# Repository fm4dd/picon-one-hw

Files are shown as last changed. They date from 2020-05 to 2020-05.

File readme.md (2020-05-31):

## PiCon-One

### Description

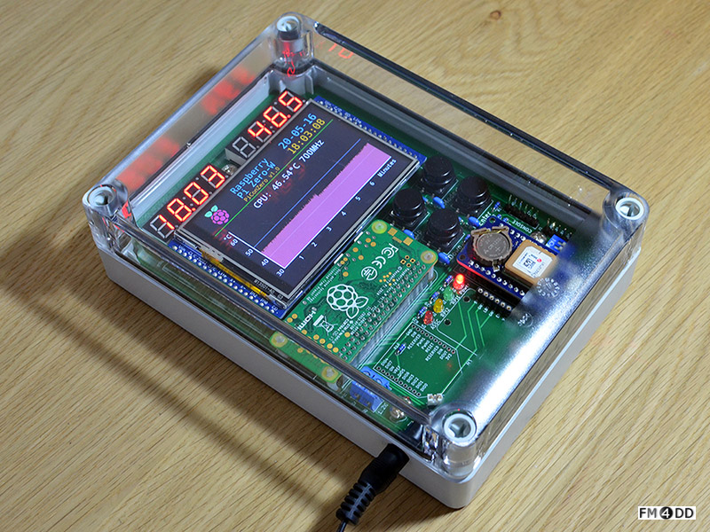
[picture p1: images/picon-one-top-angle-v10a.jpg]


PiCon-One is a multi-function controller for automation and industrial use cases.
At its heart is the smallest member of the Raspberry family, the Raspberry Pi Zero W.
Instead of adding a "hat" on top of the Raspberry, I reversed the roles:
The Pi becomes the "hat" for the controller mainboard, which has been fitted to 
a Takachi enclosure.

The design aims to add flexible power configuration, real-time clock, GPS positioning,
display and communication interfaces, enabling rapid prototyping under the widespread
Raspberry Pi ecosystem.

### Schematic
[PiCon-One Schematics](picon-one-schematics-v10a.pdf)

### PCB Gerber

Layers: 2
Dimension: 118mm x 168mm
PCB Thickness: 1.6
PCB Color: Green
Surface Finish: LeadFree HASL-RoHS
Copper Weight: 1
Material: FR4-Standard Tg 130-140C
Gerber: [PiCon-One Gerber V1.0a](picon-one-gerber-v10a.zip)

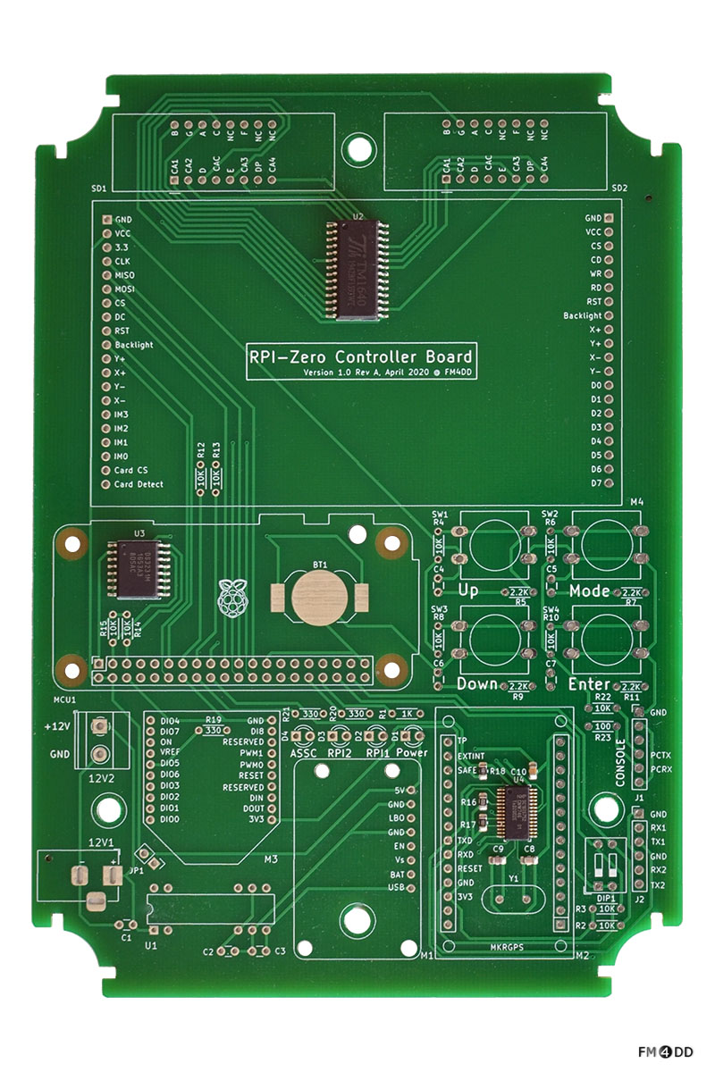
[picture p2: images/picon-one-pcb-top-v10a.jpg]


### Components Layout

Takachi Enclosure: SPCP131805T, 125mm x 175mm x 50mm

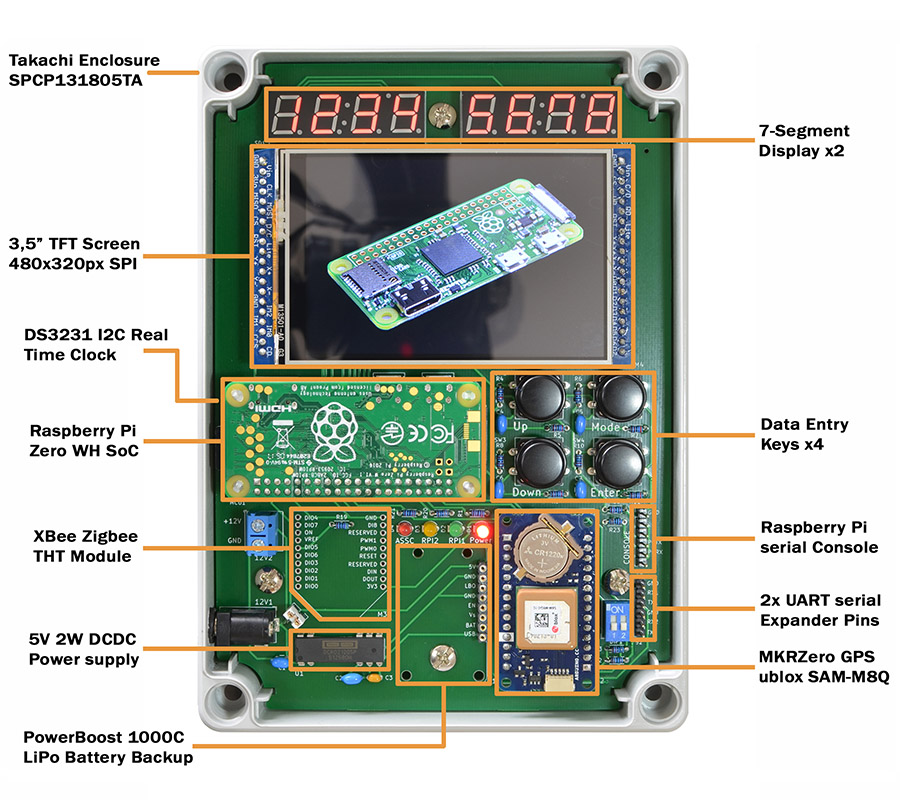
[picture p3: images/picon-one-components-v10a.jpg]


### Bill of Materials

[BOM file PiCon-One v1.0a](./picon-one-bom-v10a.csv)

### Assembly

SMT parts assembly has been combined with PCB manufacturing. 
Remaining is the THT parts assembly.

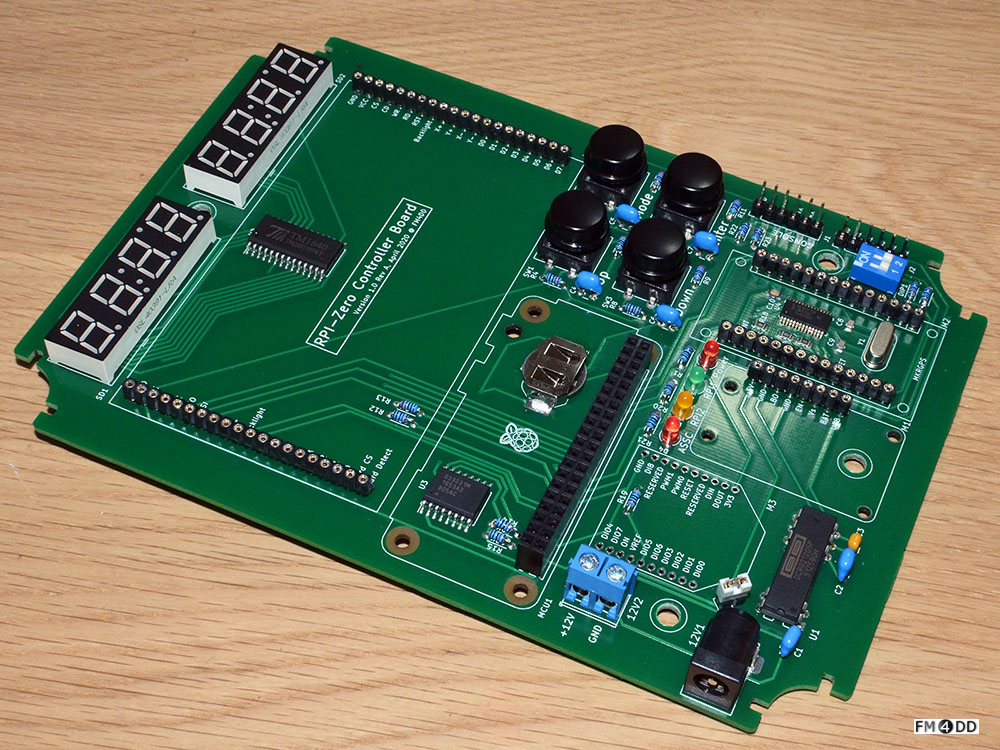
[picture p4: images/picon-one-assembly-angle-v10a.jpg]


#### Software and Drivers

Example software and setup is kept in a separate github repo at
https://github.com/fm4dd/picon-one-sw

### License

CERN Open Hardware Licence v1.2

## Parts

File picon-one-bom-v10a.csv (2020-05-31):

Item | Qty | Reference | Part Description | Type | Manufacturer | Manufacturer Part-# | Distributor | Distributor Part-#
1 | 1 | D2 | LED Green Diffused 3mm round | THT | Wurth Electronics Inc. | 151031VS06000 | Digi-Key | 732-5008-ND
2 | 1 | D3 | LED Yellow Diffused 3mm round | THT | Wurth Electronics Inc. | 151031YS06000 | Digi-Key | 732-5010-ND
3 | 1 | R20 | RES 330 OHM 1/4W 1% AXIAL | THT | Stackpole Electronics Inc | RNMF14FTC330R | Digi-Key | S330CACT-ND
4 | 1 | R21 | RES 220 OHM 1/4W 1% AXIAL | THT | Stackpole Electronics Inc | RNMF14FTC220R | Digi-Key | S220CACT-ND
5 | 1 | R22 | RES 10K OHM 1/4W 1% AXIAL | THT | Stackpole Electronics Inc | RNMF14FTC10K0 | Digi-Key | S10KCACT-ND
6 | 1 | R23 | RES 100 OHM 1/4W 1% AXIAL | THT | Stackpole Electronics Inc | RNMF14FTC100R | Digi-Key | S100CACT-ND
7 | 2 | J1, J2 | 2x 2.54-pin x6 header for serial pinout | THT | N/A | N/A | Digi-Key | N/A
Item | Qty | Reference | Part Description | Type | Manufacturer | Manufacturer Part-# | Distributor | Distributor Part-#
8 | 1 | 12V1 | Barrel Jack Connector 2.1mm | THT | CUI Inc. | PJ-002A | Digi-Key | CP-002A-ND
9 | 1 | 12V2 | TERM BLK 2P SIDE ENT 5.08MM PCB | THT | On Shore Technology Inc. | OSTTC022162 | Digi-Key | ED2609-ND
10 | 1 | U1 | DC DC CONVERTER 5V 2W | THT | Texas Instruments | DCR021205P | Digi-Key | 296-36927-5-ND
11 | 1 | C1 | CAP CER 2.2pF 50V C0G Radial | THT | TDK | FG28C0G1H2R2CNT06 | Digi-Key | 445-173491-1-ND
12 | 1 | C2 | CAP CER 1UF 50V X8L Radial | THT | KEMET | C320C105K5N5TA91707301 | Digi-Key | 399-14394-1-ND
13 | 1 | C3 | CAP CER 0.1UF 50V X7R RADIAL | THT | AVX | SR215C104KAT | Digi-Key | SR215C104KAT-ND
14 | 1 | R1 | RES 1K OHM 1/4W 1% AXIAL | THT | Stackpole Electronics Inc | RNMF14FTC1K0 | Digi-Key | S1KCACT-ND
15 | 1 | D1 | LED Red Diffused 3mm round | THT | Wurth Electronics Inc. | 151031SS04000 | Digi-Key | 732-5005-ND
16 | 1 | M1 | PWRBOOST 1000 5V LIPO USB | THT | Adafruit Industries LLC | 2465 | Digi-Key | 1528-1349-ND
17 | 1 | JP1 | 2x 2.54-pin header and Jumper | THT |  |  | Digi-Key
Item | Qty | Reference | Part Description | Type | Manufacturer | Manufacturer Part-# | Distributor | Distributor Part-#
18 | 1 | M2 | Arduino MKR GPS Shield | THT | Arduino | ASX00017 | Digi-Key | 1050-1171-ND
Item | Qty | Reference | Part Description | Type | Manufacturer | Manufacturer Part-# | Distributor | Distributor Part-#
19 | 2 | DS1, DS2 | 0.39 Inch 4-Digit 7-Segment Display | THT | OptoSupply | OSL40391-LRA | Akizuki | I-09971
20 | 1 | U2 | TM1640 LED driver IC | SMT | Titan Microelectronics | TM1640 | LCSC | C41327
21 | 2 | R12, R13 | RES 10K OHM 1/4W 1% AXIAL | THT | Stackpole Electronics Inc | RNMF14FTC10K0 | Digi-Key | S10KCACT-ND
Item | Qty | Reference | Part Description | Type | Manufacturer | Manufacturer Part-# | Distributor | Distributor Part-#
22 | 1 | DIP1 | DIP SWITCH, SPST, 2.54 PITCH, RA | THT | CUI Devices | DS01-254-S-02BE | Digi-Key | 2223-DS01-254-S-02BE-ND
23 | 4 | SW1-SW4 | 12mm SWITCH TACTILE SPST-NO 0.05A 24V | THT | TE Connectivity | FSM103 | Digi-Key | 450-1158-ND
24 | 4 | C4, C5, C6, C7 | CAP CER 1UF 50V X8L Radial | THT | KEMET | C320C105K5N5TA91707301 | Digi-Key | 399-14394-1-ND
25 | 6 | R2-4, R6, R8, R10 | RES 10K OHM 1/4W 1% AXIAL | THT | Stackpole Electronics Inc | RNMF14FTC10K0 | Digi-Key | S10KCACT-ND
26 | 4 | R5, R7, R9, R11 | RES 2K2 OHM 1/4W 1% AXIAL | THT | Stackpole Electronics Inc | RNMF14FAD2K20 | Digi-Key | RNMF14FAD2K20CT-ND
Item | Qty | Reference | Part Description | Type | Manufacturer | Manufacturer Part-# | Distributor | Distributor Part-#
27 | 1 | M3 | Xbee RF TXRX Module S2C | THT | Digi International | XB24CZ7PIT-004 | Digi-Key | 602-1557-ND
28 | 1 | R19 | RES 330 OHM 1/4W 1% AXIAL | THT | Stackpole Electronics Inc | RNMF14FTC330R | Digi-Key | S330CACT-ND
29 | 1 | D4 | LED Red Diffused 3mm round | THT | Wurth Electronics Inc. | 151031SS04000 | Digi-Key | 732-5005-ND
Item | Qty | Reference | Part Description | Type | Manufacturer | Manufacturer Part-# | Distributor | Distributor Part-#
30 | 1 | MCU1 | Raspberry Pi Zero W BCM2835 | NA | Pi Supply | RPI-027 | Digi-Key | 1910-1000-ND
31 | 1 | N/A | CONN RCPT 40POS 0.1 TIN PCB | THT | Harwin Inc. | M20-7832046 | Digi-Key | 952-2150-ND
32 | 4 | N/A | BOARD SUPRT SNAP LOCK NYLON 11MM | NA | W�rth Elektronik | 709670110 | Digi-Key | 732-10378-ND
Item | Qty | Reference | Part Description | Type | Manufacturer | Manufacturer Part-# | Distributor | Distributor Part-#
33 | 1 | M4 | 3.5" TFT 320X480 Touchscreen | THT | Adafruit Industries LLC | 2050 | Digi-Key | 1528-1470-ND
34 | 1 | N/A | 40-pin Socket 2.54mm single row | THT | Neltron Industrial Co., Ltd. | 6604-S | Akizuki | P-01591
35 | 2 | N/A | 2.54mm Pin Header Strip, Straight, Single Row | THT | Useconn Electronics, Ltd | PHA-1x40SG-XX | Akizuki | C-06637
Item | Qty | Reference | Part Description | Type | Manufacturer | Manufacturer Part-# | Distributor | Distributor Part-#
36 | 1 | U3 | DS3231 I2C Real Time Clock IC | SMT | Maxim Integrated | DS3231M+TRL | LCSC | C37663
37 | 1 | BT1 | BATTERY RETAINER COIN 12MM SMD | SMT | Linx Technologies Inc. | BAT-HLD-012-SMT | Digi-Key | BAT-HLD-012-SMT-ND
38 | 2 | R14, R15 | RES 10K OHM 1/4W 1% AXIAL | THT | Stackpole Electronics Inc | RNMF14FTC10K0 | Digi-Key | S10KCACT-ND
Item | Qty | Reference | Part Description | Type | Manufacturer | Manufacturer Part-# | Distributor | Distributor Part-#
39 | 1 | N/A | SPCP IP67 POLYCARBONATE ENCLOSURE | NA | Takachi | SPCP131805T | Amazon | N/A
40 | 4 | N/A | MACH SCREW BINDING HEAD COMBO M4 | NA | Keystone Electronics | 7799-1 | Digi-Key | 36-7799-1-ND
Item | Qty | Reference | Part Description | Type | Manufacturer | Manufacturer Part-# | Distributor | Distributor Part-#
41 | 1 | U4 | SC16IS752 Dual UART IC | SMT | NXP | SC16IS752IPW,128 | Digi-Key | 568-11944-1-ND
42 | 1 | Y1 | CRYSTAL 14.74560MHZ 30PF | THT | IQD Frequency Products | LFXTAL003224BULK | Digi-Key | 1923-1432-ND
43 | 1 | C8 | CAP 22pF 10% 50V X7R C_0805 | SMT | Samsung | CL21C220JBANNNC | LCSC | C1804
44 | 1 | C9 | CAP 33pF 5% 50V C_0805 | SMT | Samsung | CL21C330JBANNNC | LCSC | C1814
45 | 1 | C10 | CAP 100nF 5% 50V X7R C_0805 | SMT | Samsung | CL21B104JBCNNNC | LCSC | C62912
46 | 1 | R16 | RES 10K OHM 1% R_0805 | SMT | Uniroyal Elec | 0805W8F1002T5E | LCSC | C17414
47 | 2 | R17,R18 | RES 1K OHM 1% R_0805 | SMT | Uniroyal Elec | 0805W8F1001T5E | LCSC | C17513

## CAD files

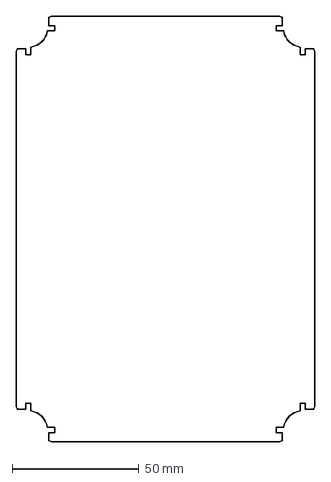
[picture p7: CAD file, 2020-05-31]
cad/20200419 pcb board outline v1.0.dxf
117.8 x 168.0 mm

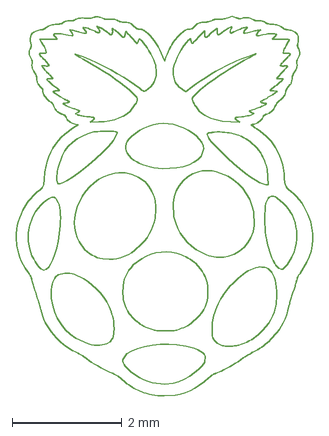
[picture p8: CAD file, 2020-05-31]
cad/20200308 raspi-logo.dxf
5.40 x 6.91 mm

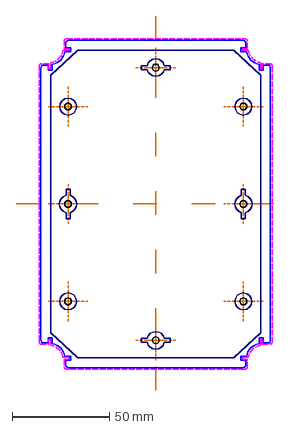
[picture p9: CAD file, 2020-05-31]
cad/20200419 Takachi encl and pcb board v1.0.dxf
132.0 x 192.0 mm

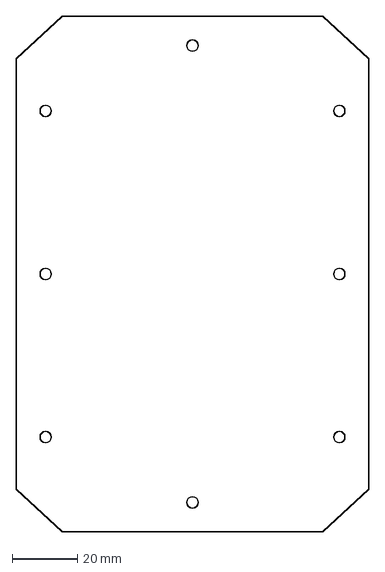
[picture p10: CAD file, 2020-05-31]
cad/20200308 pcb board-footprint-space-v1.0.dxf
108.0 x 158.0 mm

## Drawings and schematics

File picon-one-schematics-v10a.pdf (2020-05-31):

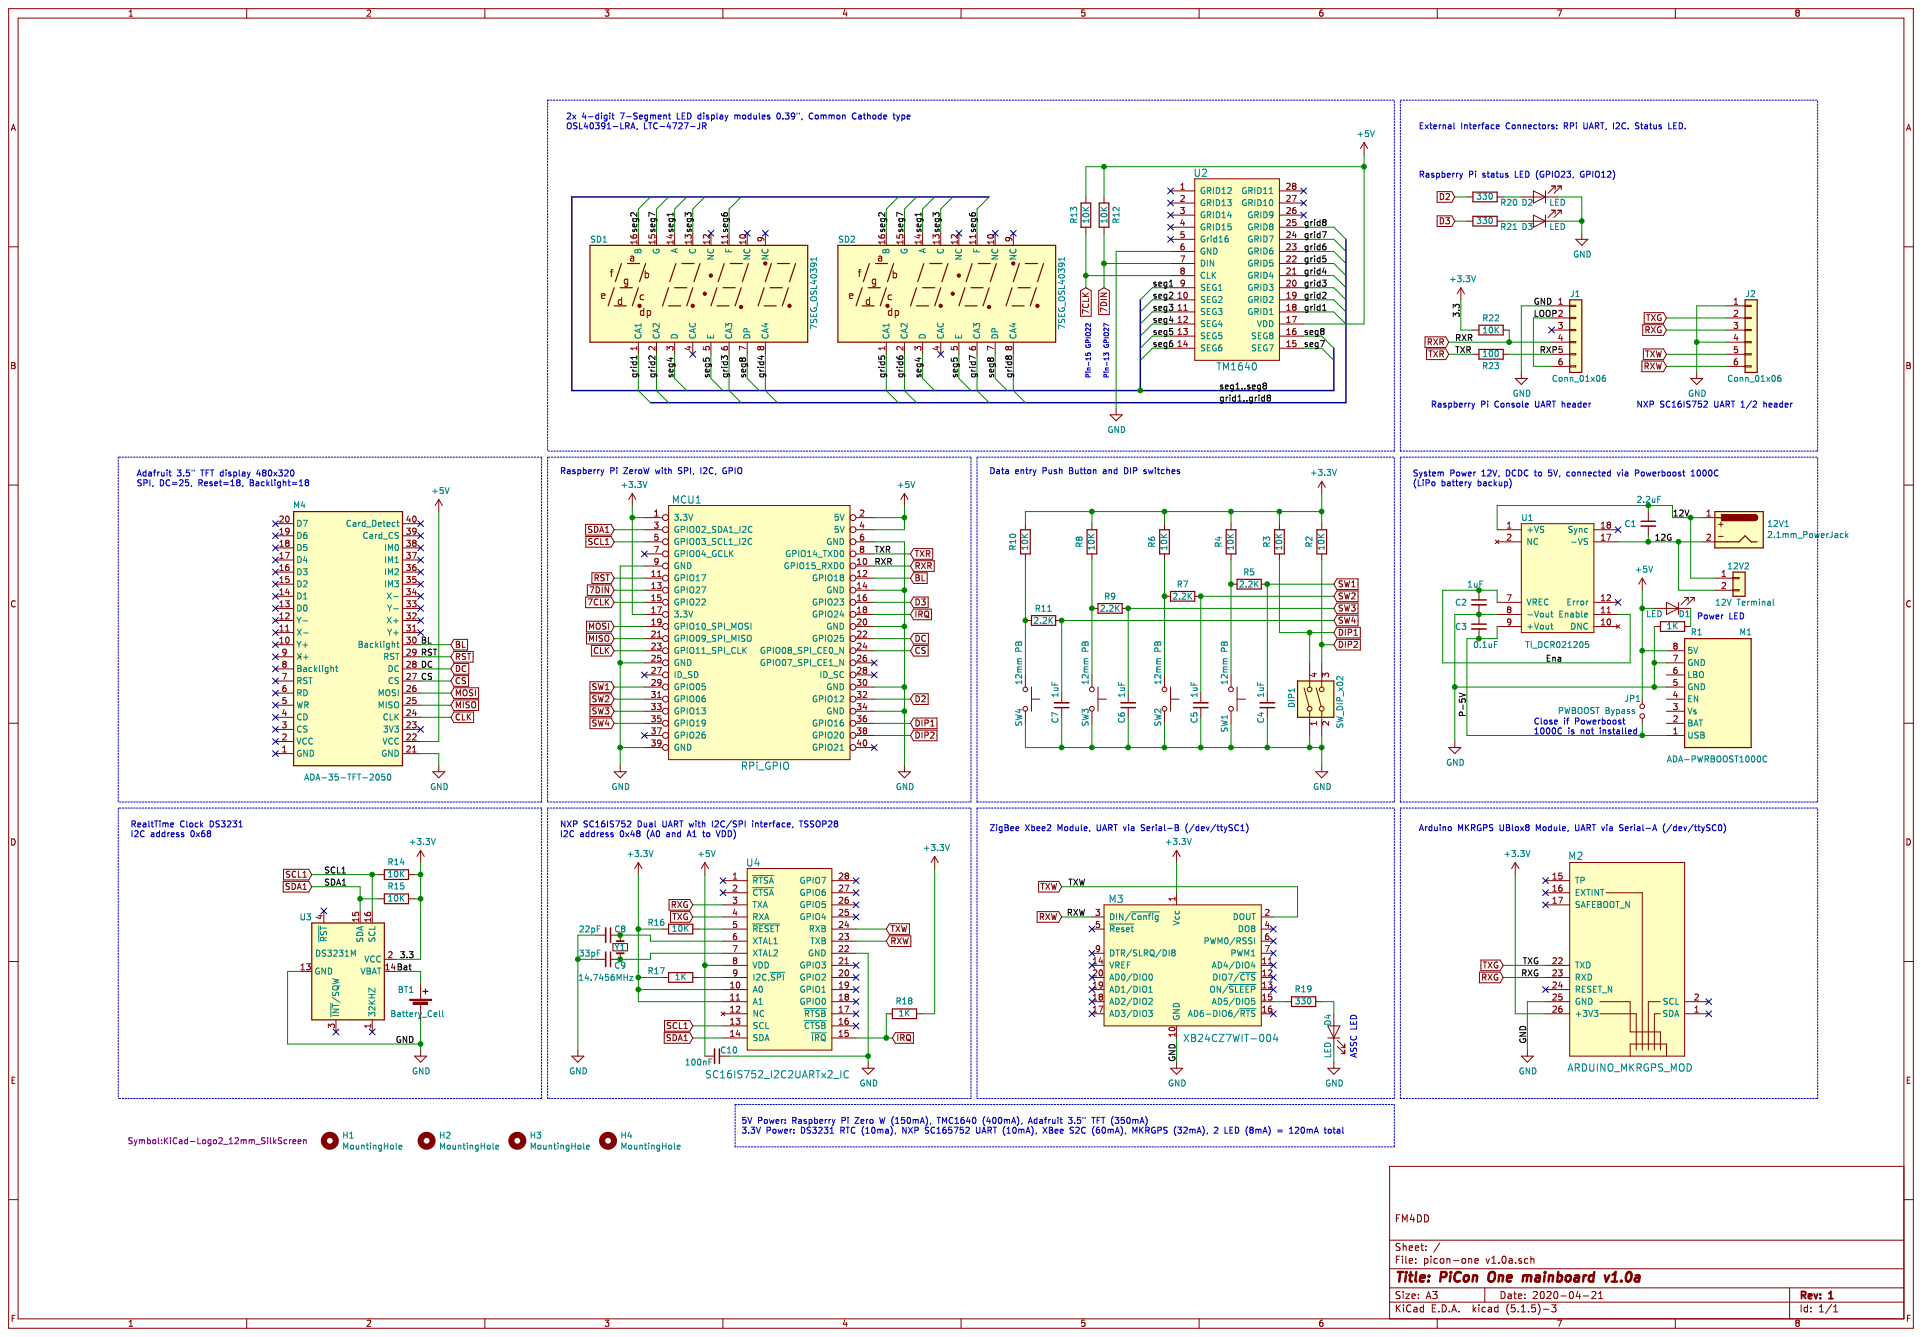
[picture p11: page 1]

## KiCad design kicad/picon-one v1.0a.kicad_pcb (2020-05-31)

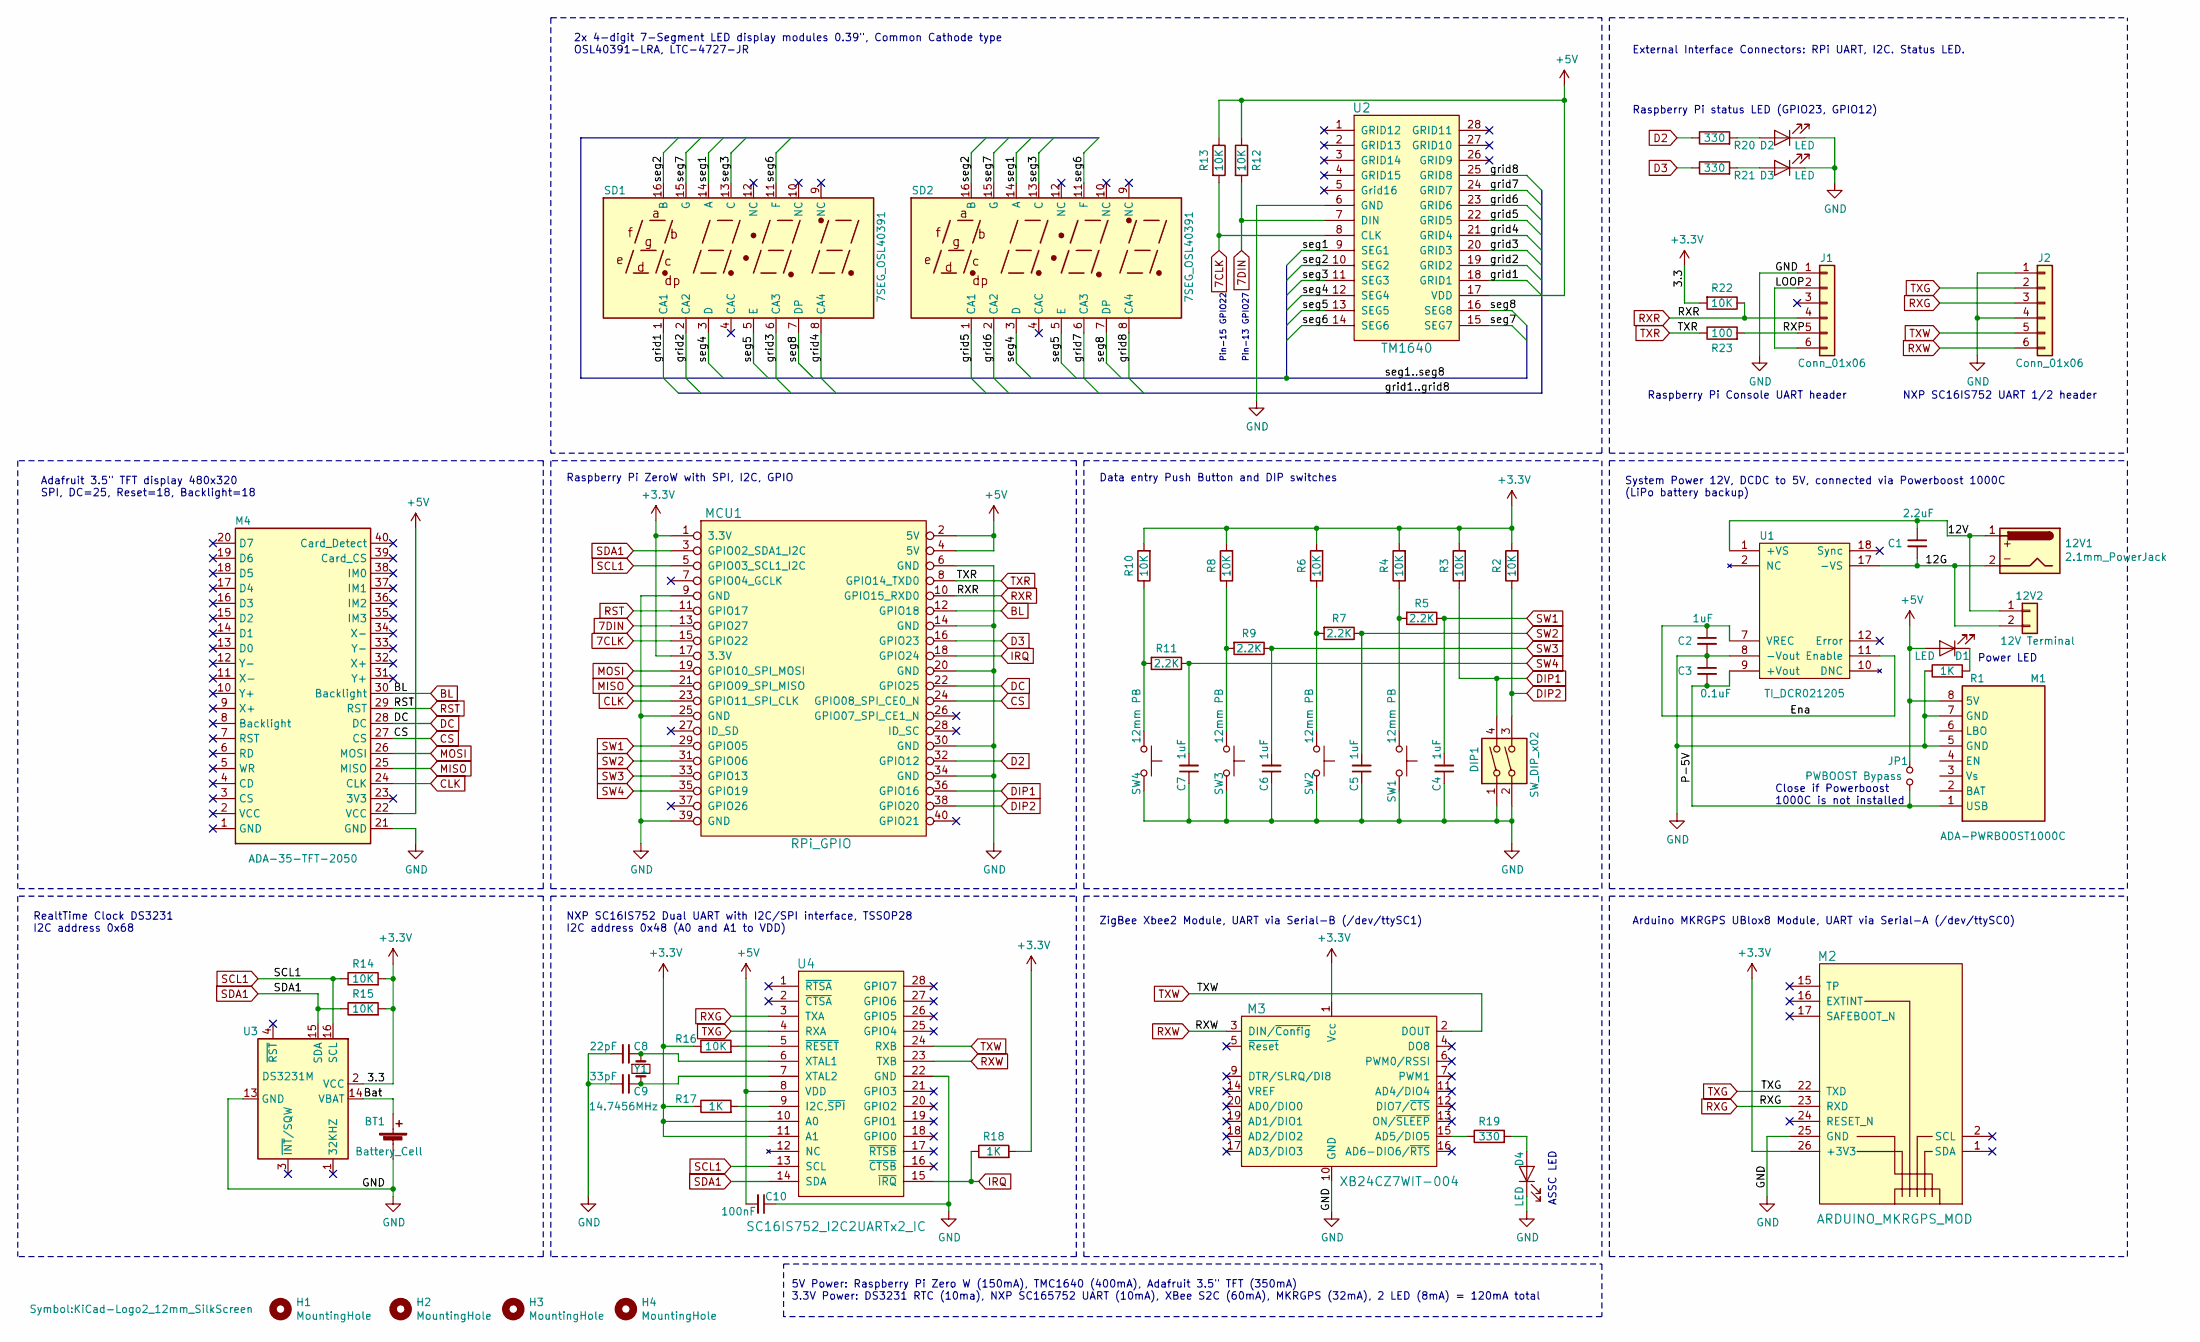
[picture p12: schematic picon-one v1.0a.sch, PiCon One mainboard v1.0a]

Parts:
12V1: 2.1mm_PowerJack; BarrelJack_2.1mm
12V2: 12V Terminal; TerminalBlock_Phoenix_MKDS-1,5-2-5.08_1x02_P5.08mm_Horizont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
BT1: Battery_Cell; BatteryHolder_LINX_BAT-HLD-012-SMT
C1: 2.2uF; C_Disc_D3.0mm_W1.6mm_P2.50mm
C2, C4, C5, C6, C7: 1uF; C_Disc_D3.0mm_W1.6mm_P2.50mm
C3: 0.1uF; C_Disc_D3.0mm_W1.6mm_P2.50mm
C8: 22pF; C_0805_2012Metric_Pad1.15x1.40mm_HandSolder
C9: 33pF; C_0805_2012Metric_Pad1.15x1.40mm_HandSolder
C10: 100nF; C_0805_2012Metric_Pad1.15x1.40mm_HandSolder
D1, D2, D3, D4: LED; LED_D3.0mm
DIP1: SW_DIP_x02; SW_DIP_SPSTx02_Slide_9.78x7.26mm_W7.62mm_P2.54mm
H1, H2, H3, H4: MountingHole; MountingHole_3.2mm_M3
J1, J2: Conn_01x06; PinHeader_1x06_P2.54mm_Vertical
JP1: PWBOOST Bypass; PinHeader_1x02_P2.54mm_Vertical
L1: Logo_KiCad; KiCad-Logo2_12mm_SilkScreen
M1: ADA-PWRBOOST1000C
M2: ARDUINO_MKRGPS_MOD; Arduino_MKRGPS
M3: XB24CZ7WIT-004; XBEE-20_THT; MPN XB24CZ7WIT-004; Digi-Key_PN 602-1560-ND
M4: ADA-35-TFT-2050; ADA-35-TFT-2050-no-ears
MCU1: RPi_GPIO; RasPi0_FaceDown
R1: 1K; R_Axial_DIN0204_L3.6mm_D1.6mm_P5.08mm_Horizontal
R2, R3, R4, R6, R8, R10, R12, R13, R14, R15, R22: 10K; R_Axial_DIN0204_L3.6mm_D1.6mm_P5.08mm_Horizontal
R5, R7, R9, R11: 2.2K; R_Axial_DIN0204_L3.6mm_D1.6mm_P5.08mm_Horizontal
R16: 10K; R_0805_2012Metric_Pad1.15x1.40mm_HandSolder
R17, R18: 1K; R_0805_2012Metric_Pad1.15x1.40mm_HandSolder
R19, R20, R21: 330; R_Axial_DIN0204_L3.6mm_D1.6mm_P5.08mm_Horizontal
R23: 100; R_Axial_DIN0204_L3.6mm_D1.6mm_P5.08mm_Horizontal
SD1, SD2: 7SEG_OSL40391; 7SEG-OSL40391
SW1, SW2, SW3, SW4: 12mm PB; SW_PUSH-12mm
U1: TI_DCR021205; TI_DCR01
U2: TM1640; SOP-28_7.5x17.9mm_P1.27mm
U3: DS3231M; SOIC-16W_7.5x10.3mm_P1.27mm
U4: SC16IS752_I2C2UARTx2_IC; TSSOP-28_4.4x9.7mm_P0.65mm
Y1: 14.7456MHz; Crystal_HC49-4H_Vertical

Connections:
7CLK: MCU1.15 (GPIO22), R13.2, U2.8 (CLK)
7DIN: MCU1.13 (GPIO27), R12.2, U2.7 (DIN)
+3V3: M2.26 (+3V3), M3.1 (Vcc), MCU1.1 (3.3V), MCU1.17 (3.3V), R2.2, R3.2, R4.2, R6.2, R8.2, R10.2, R14.2, R15.2, R16.1, R17.1, R18.2, R22.2, U3.2 (VCC), U4.10 (A0), U4.11 (A1)
+5V: C10.2, D1.2 (A), JP1.2, M1.8 (5V), M4.22 (VCC), MCU1.2 (5V), MCU1.4 (5V), R12.1, R13.1, U2.17 (VDD), U4.8 (VDD)
/12G: 12V1.2, 12V2.2, C1.2, U1.17 (-VS)
/12V: 12V1.1, 12V2.1, C1.1, U1.1 (+VS)
/Bat: BT1.1 (+), U3.14 (VBAT)
/Ena: C2.1, U1.7 (VREC), U1.11 (Enable)
/LOOP: J1.2, J1.6
/P-5V: C3.2, JP1.1, M1.1 (USB), U1.9 (+Vout)
/RXP: J1.5, R23.2
/grid1: SD1.1 (CA1), U2.18 (GRID1)
/grid2: SD1.2 (CA2), U2.19 (GRID2)
/grid3: SD1.6 (CA3), U2.20 (GRID3)
/grid4: SD1.8 (CA4), U2.21 (GRID4)
/grid5: SD2.1 (CA1), U2.22 (GRID5)
/grid6: SD2.2 (CA2), U2.23 (GRID6)
/grid7: SD2.6 (CA3), U2.24 (GRID7)
/grid8: SD2.8 (CA4), U2.25 (GRID8)
/seg1: SD1.14 (A), SD2.14 (A), U2.9 (SEG1)
/seg2: SD1.16 (B), SD2.16 (B), U2.10 (SEG2)
/seg3: SD1.13 (C), SD2.13 (C), U2.11 (SEG3)
/seg4: SD1.3 (D), SD2.3 (D), U2.12 (SEG4)
/seg5: SD1.5 (E), SD2.5 (E), U2.13 (SEG5)
/seg6: SD1.11 (F), SD2.11 (F), U2.14 (SEG6)
/seg7: SD1.15 (G), SD2.15 (G), U2.15 (SEG7)
/seg8: SD1.7 (DP), SD2.7 (DP), U2.16 (SEG8)
BL: M4.30 (Backlight), MCU1.12 (GPIO18)
CLK: M4.24 (CLK), MCU1.23 (GPIO11_SPI_CLK)
CS: M4.27 (CS), MCU1.24 (GPIO08_SPI_CE0_N)
D2: MCU1.32 (GPIO12), R20.1
D3: MCU1.16 (GPIO23), R21.1
DC: M4.28 (DC), MCU1.22 (GPIO25)
DIP1: DIP1.4, MCU1.36 (GPIO16), R3.1
DIP2: DIP1.3, MCU1.38 (GPIO20), R2.1
GND: BT1.2 (-), C2.2, C3.1, C4.1, C5.1, C6.1, C7.1, C8.2, C9.2, C10.1, D2.1 (K), D3.1 (K), D4.1 (K), DIP1.1, DIP1.2, J1.1, J2.1, J2.4, M1.5 (GND), M1.7 (GND), M2.25 (GND), M3.10 (GND), M4.21 (GND), MCU1.6 (GND), MCU1.9 (GND), MCU1.14 (GND), MCU1.20 (GND), MCU1.25 (GND), MCU1.30 (GND), MCU1.34 (GND), MCU1.39 (GND), R1.1, SW1.2, SW2.2, SW3.2, SW4.2, U1.8 (-Vout), U2.6 (GND), U3.5 (GND), U3.6 (GND), U3.7 (GND), U3.8 (GND), U3.9 (GND), U3.10 (GND), U3.11 (GND), U3.12 (GND), U3.13 (GND), U4.22 (GND)
IRQ: MCU1.18 (GPIO24), R18.1, U4.15 (~IRQ)
MISO: M4.25 (MISO), MCU1.21 (GPIO09_SPI_MISO)
MOSI: M4.26 (MOSI), MCU1.19 (GPIO10_SPI_MOSI)
unnamed: C8.1, U4.6 (XTAL1), Y1.1
unnamed: C9.1, U4.7 (XTAL2), Y1.2
unnamed: D1.1 (K), R1.2
unnamed: D2.2 (A), R20.2
unnamed: D3.2 (A), R21.2
unnamed: D4.2 (A), R19.2
unnamed: M3.15 (AD5/DIO5), R19.1
unnamed: R4.1, R5.2, SW1.1
unnamed: R6.1, R7.2, SW2.1
unnamed: R8.1, R9.2, SW3.1
unnamed: R10.1, R11.2, SW4.1
unnamed: R16.2, U4.5 (~RESET)
unnamed: R17.2, U4.9 (I2C,~SPI)
RST: M4.29 (RST), MCU1.11 (GPIO17)
RXG: J2.3, M2.23 (RXD), U4.3 (TXA)
RXR: J1.4, MCU1.10 (GPIO15_RXD0), R22.1
RXW: J2.6, M3.3 (DIN/~Config), U4.23 (TXB)
SCL1: MCU1.5 (GPIO03_SCL1_I2C), R14.1, U3.16 (SCL), U4.13 (SCL)
SDA1: MCU1.3 (GPIO02_SDA1_I2C), R15.1, U3.15 (SDA), U4.14 (SDA)
SW1: C4.2, MCU1.29 (GPIO05), R5.1
SW2: C5.2, MCU1.31 (GPIO06), R7.1
SW3: C6.2, MCU1.33 (GPIO13), R9.1
SW4: C7.2, MCU1.35 (GPIO19), R11.1
TXG: J2.2, M2.22 (TXD), U4.4 (RXA)
TXR: MCU1.8 (GPIO14_TXD0), R23.1
TXW: J2.5, M3.2 (DOUT), U4.24 (RXB)

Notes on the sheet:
RealtTime Clock DS3231 I2C address 0x68
Adafruit 3.5" TFT display 480x320 SPI, DC=25, Reset=18, Backlight=18
Raspberry Pi ZeroW with SPI, I2C, GPIO
NXP SC16IS752 Dual UART with I2C/SPI interface, TSSOP28 I2C address 0x48 (A0 and A1 to VDD)
ZigBee Xbee2 Module, UART via Serial-B (/dev/ttySC1)
Data entry Push Button and DIP switches
Arduino MKRGPS UBlox8 Module, UART via Serial-A (/dev/ttySC0)
System Power 12V, DCDC to 5V, connected via Powerboost 1000C (LiPo battery backup)
External Interface Connectors: RPi UART, I2C. Status LED.
2x 4-digit 7-Segment LED display modules 0.39", Common Cathode type OSL40391-LRA, LTC-4727-JR
Close if Powerboost 1000C is not installed
Raspberry Pi Console UART header
Raspberry Pi status LED (GPIO23, GPIO12)
5V Power: Raspberry Pi Zero W (150mA), TMC1640 (400mA), Adafruit 3.5" TFT (350mA) 3.3V Power: DS3231 RTC (10ma), NXP SC165752 UART (10mA), XBee S2C (60mA), MKRGPS (32mA), 2 LED (8mA) = 120mA total
Power LED
ASSC LED
NXP SC16IS752 UART 1/2 header
Pin-15 GPIO22
Pin-13 GPIO27

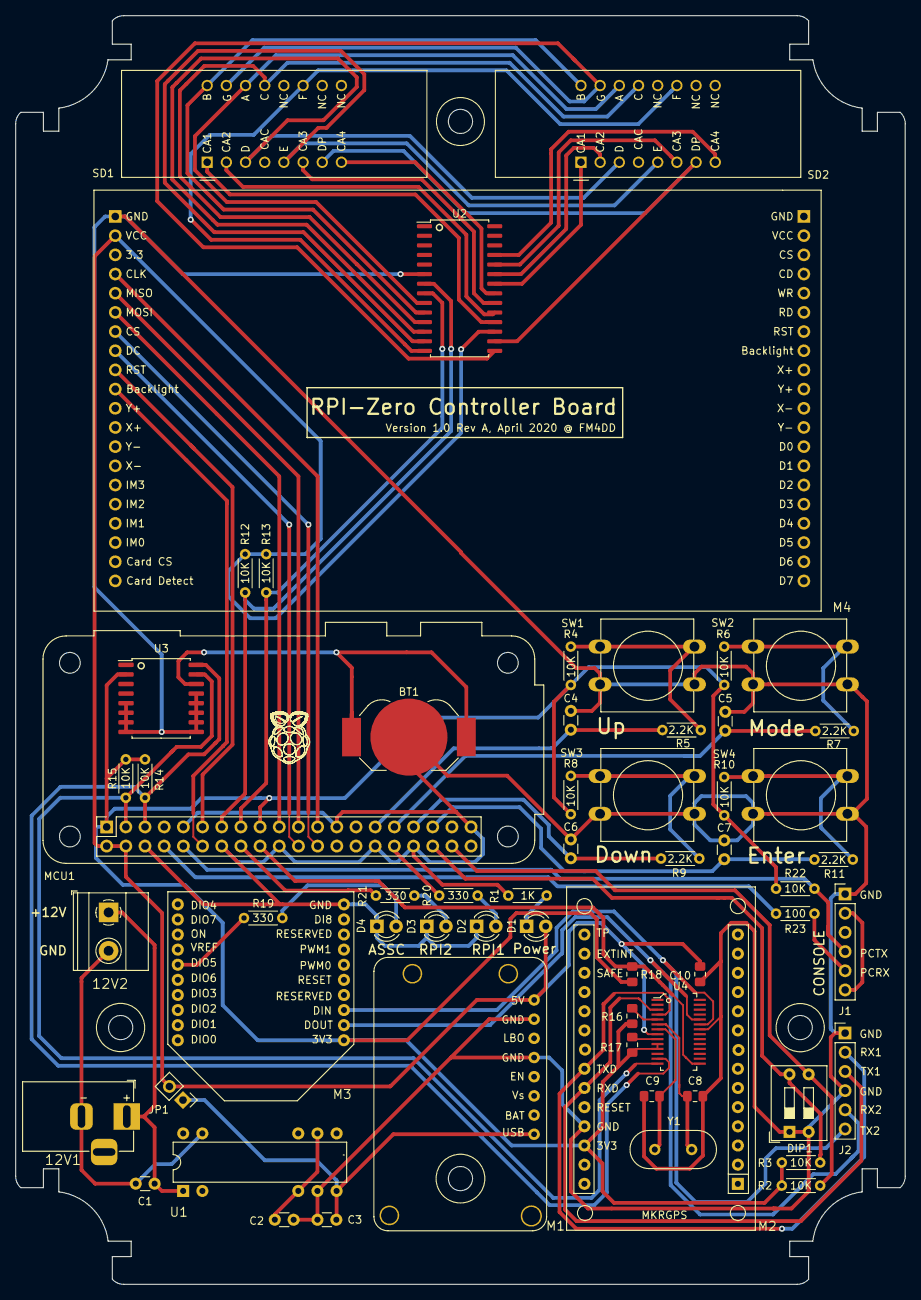
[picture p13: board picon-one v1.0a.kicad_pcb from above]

Board: 2 copper layers, 117.8 x 168.0 mm, 65 parts (1 on the bottom side), 65 nets.
